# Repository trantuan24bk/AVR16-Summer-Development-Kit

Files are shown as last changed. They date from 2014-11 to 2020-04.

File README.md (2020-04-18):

# AVR16 Summer Development Kit
 Development kit for AVR 16-bit microcontrollers

**What included?**
- Programmer software: extreme burner avr
- USB driver: usbasp
- Altium project design files

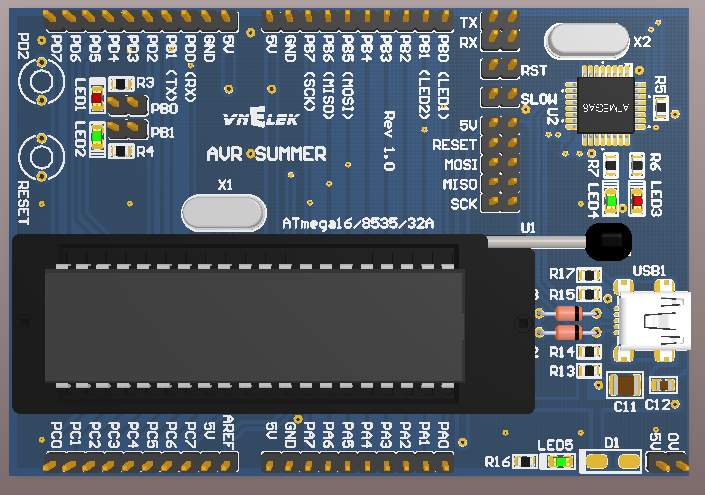
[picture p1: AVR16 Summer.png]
AVR16 Summer Development Kit


## Contribution

- Any contribute please make a pull request.
- Free to use for any purpose. Use at your own risk.

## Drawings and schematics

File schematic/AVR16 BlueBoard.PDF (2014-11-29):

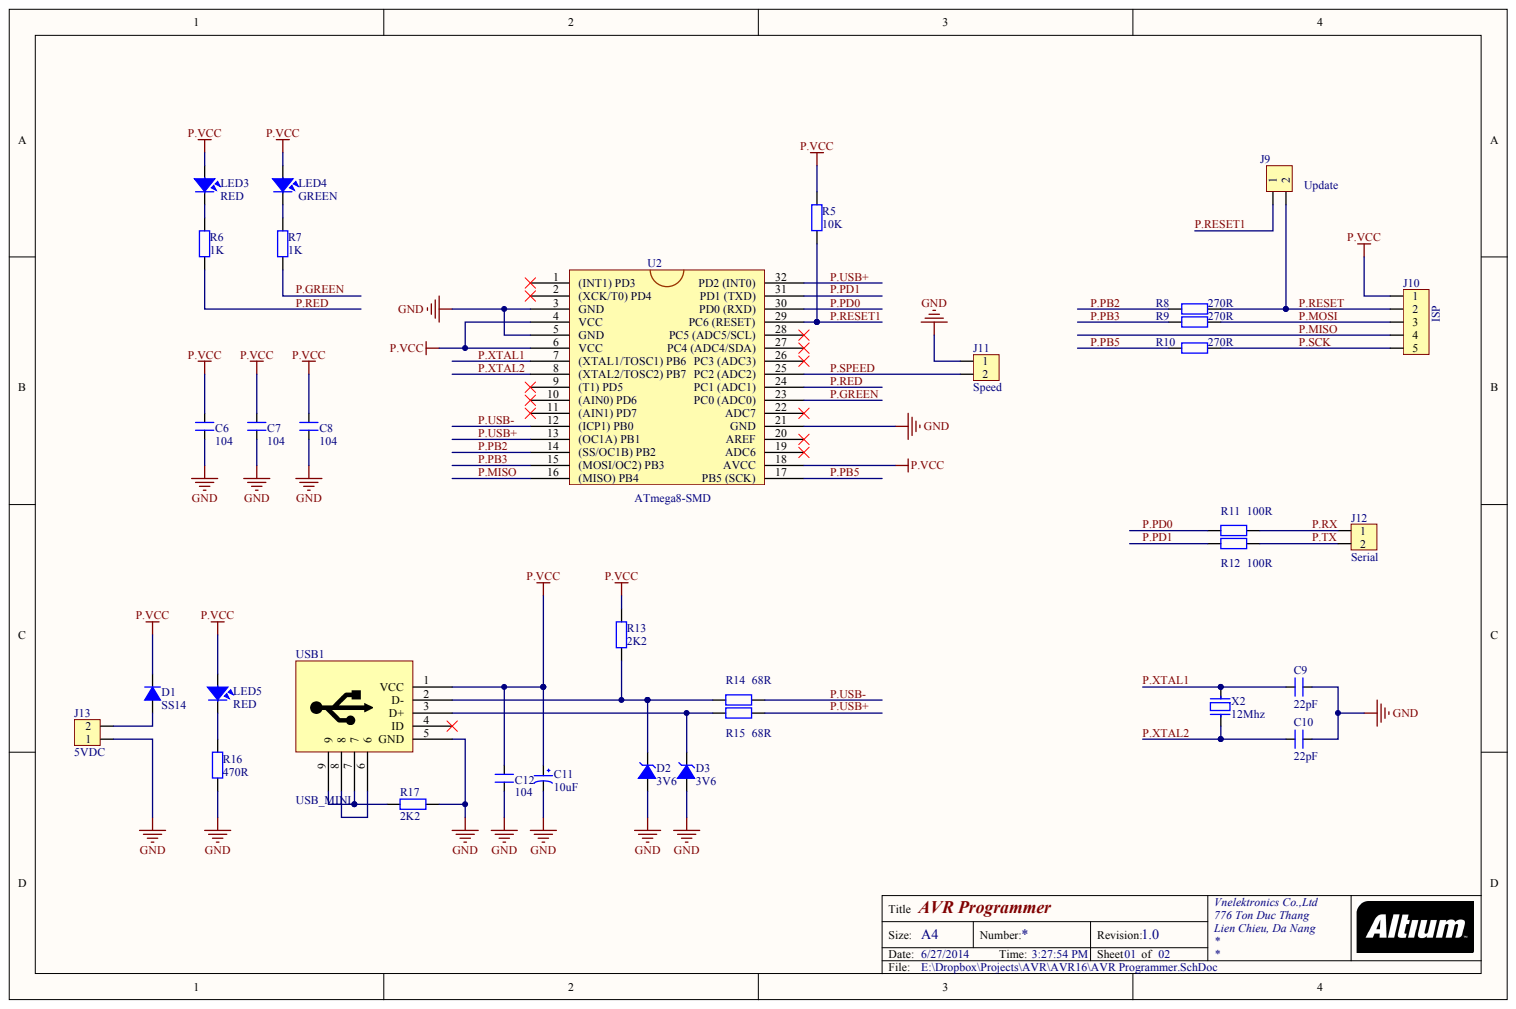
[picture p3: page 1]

4 D G | D G | D G | D G | D

Title | Vnelektro nics Co.,Ltd 7 7 6 To n D uc Th a n g Lien Chieu, D a Na n g * *

A4 Size: | N umber: | Revisio n :
Date: Time: | | Sheet 0 1 o f 0 2
File: E:\Dro p b o x\Projects\A VR\A VR1 6\A VR Pro grammer.Sch D o c

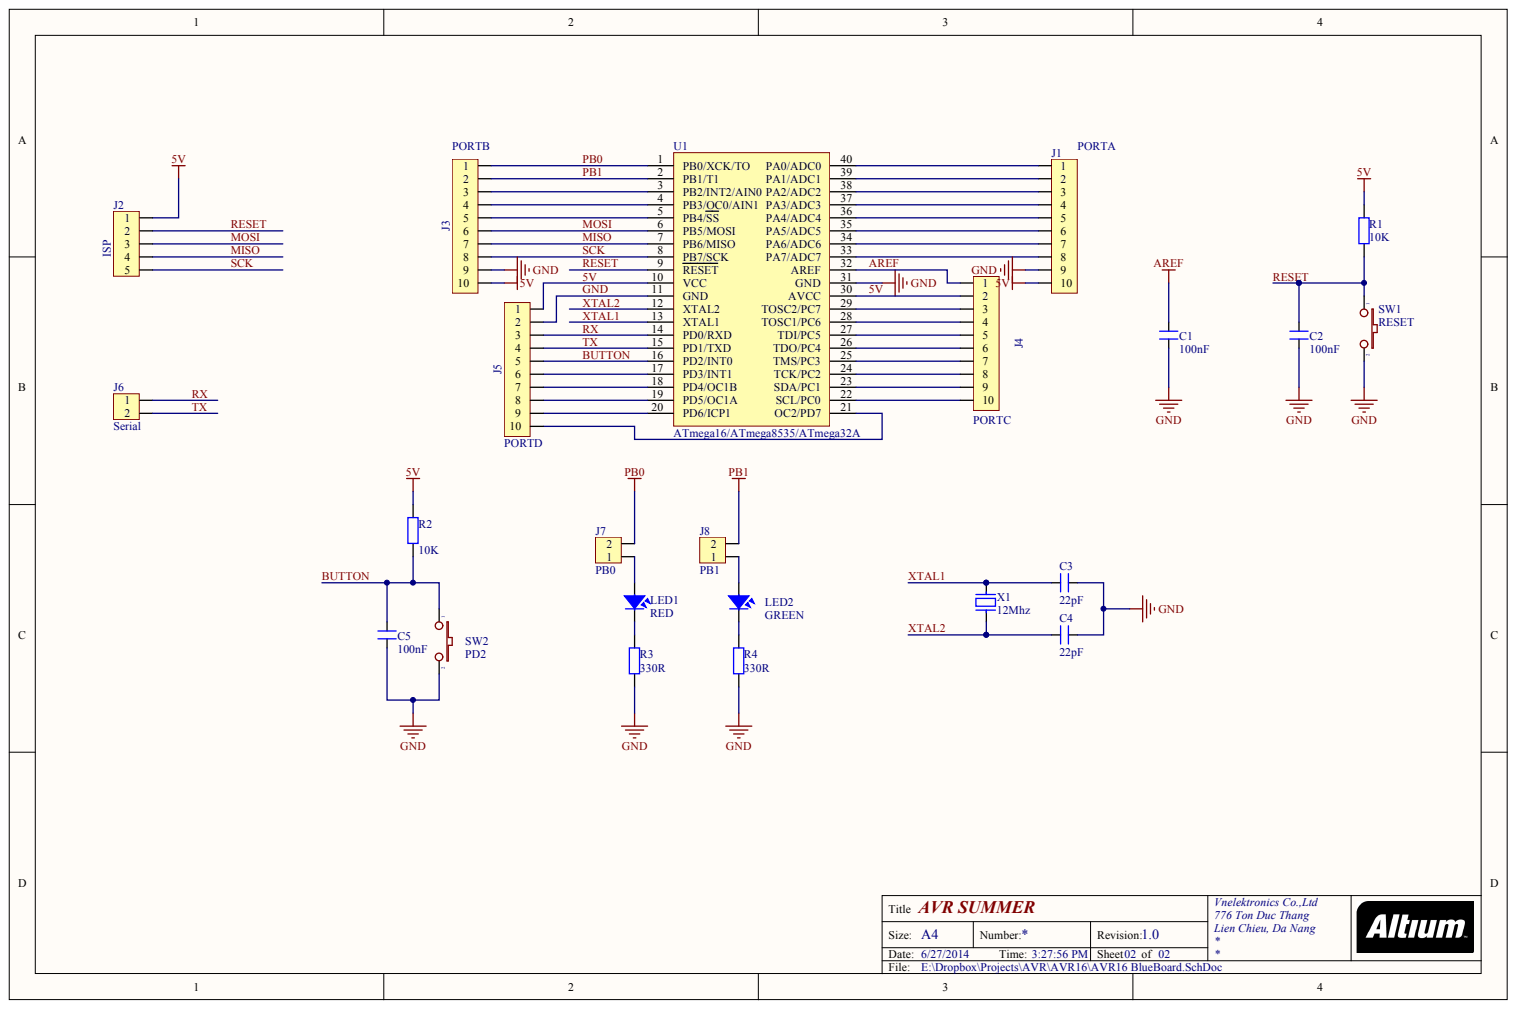
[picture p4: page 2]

5 1 0
D | 1 1 | | 5 V
XTAL2 XTAL1 | 1 2

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

A4 Size: | N umber: | Revisio n :
Date: Time: | | Sheet 0 2 o f 0 2
File: E:\Dro p b o x\Projects\A VR\A VR1 6\A VR1 6 BlueBoard.Sch D o c

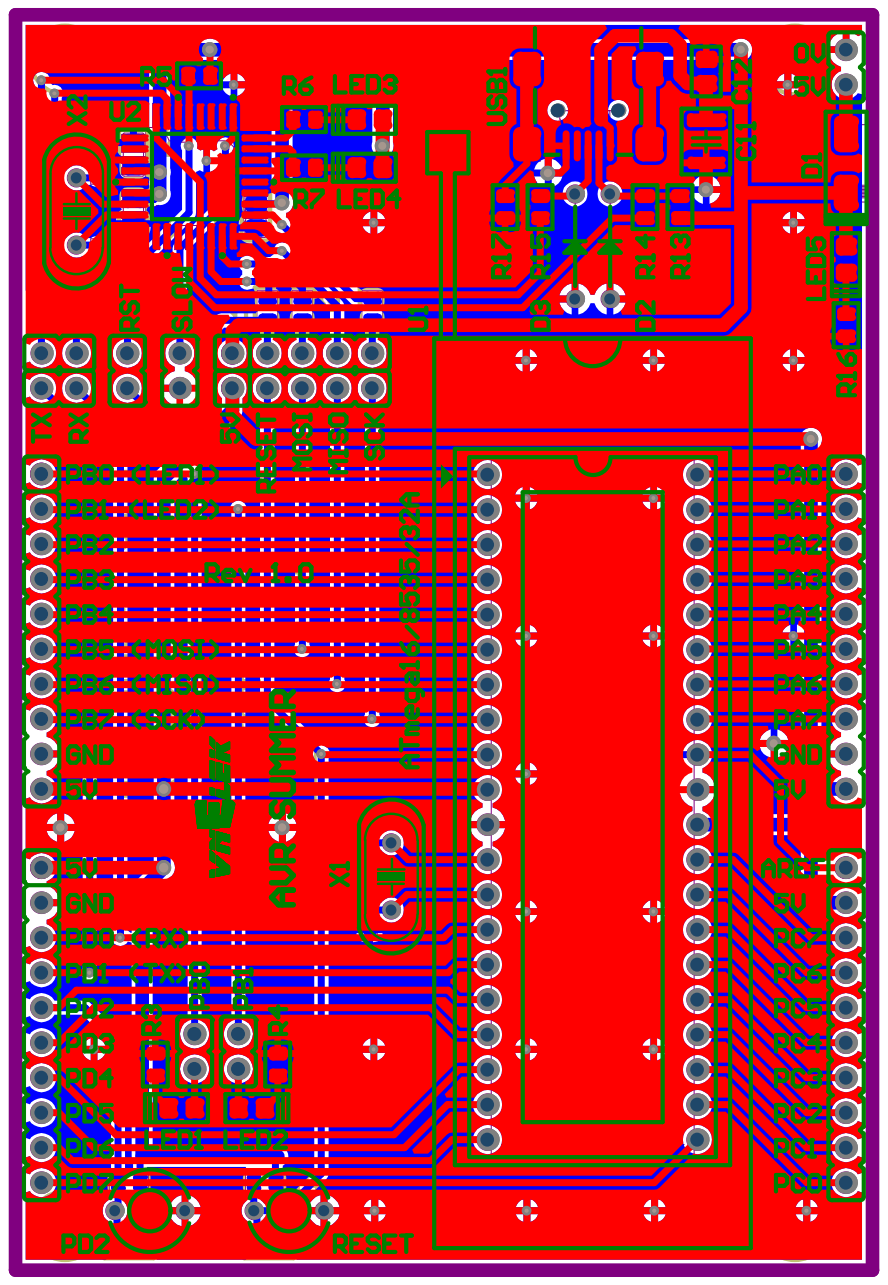
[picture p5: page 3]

Comment | Description | Designator | Footprint | LibRef | Quantity
100nF | Cap np 1pF - 472pF | C1, C2, C5 | C0805 | CN1 | 3
22pF | Cap np 1pF - 472pF | C3, C4, C9, C10 | C0603 | CN1 | 4
104 | Cap np 104 => 105pF | C6, C7, C8, C12 | C0805 | CN2 | 4
10uF | Cap P 0,1uF < 22uF , 16 - 50V | C11 | C1210 | CP1 | 1
SS14 | Diode 1A | D1 | SS14 | D1A | 1
3V6 | Diode Zenner | D2, D3 | 1N5223 | DZ | 2
PORTA | Header 10 | J1 | Header_10 | Hed10 | 1
ISP | Header 5 (Green) | J2, J10 | Header_5 | Hed5 | 2
PORTB | Header 10 | J3 | Header_10 | Hed10 | 1
PORTC | Header 10 | J4 | Header_10 | Hed10 | 1
PORTD | Header 10 | J5 | Header_10 | Hed10 | 1
Serial | Header 2 (Green) | J6, J12 | Header_2 | Hed2 | 2
PB0 | Header 2 (Green) | J7 | Header_2 | Hed2 | 1
PB1 | Header 2 (Green) | J8 | Header_2 | Hed2 | 1
Update | Header 2 (Green) | J9 | Header_2 | Hed2 | 1
Speed | Header 2 (Green) | J11 | Header_2 | Hed2 | 1
5VDC | Header 2 (Green) | J13 | Header_2 | Hed2 | 1
RED | LED Single colour Green and Red | LED1, LED3 | Led 0805R | LED | 2
GREEN | LED Single colour Green and Red | LED2, LED4 | Led 0805G | LED | 2
RED | LED Single colour Green and Red | LED5 | Led 0805G | LED | 1
Res2 | Resistor | R1, R2, R3, R4, R5, R6, R7, R8, R9, R10, R11, R12, R13, R14, R15, R16, R17 | RESC2012(0805) | Res2 | 17
RESET | Switch button 2 pin | SW1 | BUTTON 2PIN TRON | SW2 | 1
PD2 | Switch button 2 pin | SW2 | BUTTON 2PIN TRON | SW2 | 1
ATmega16/ATmega8535 /ATmega32A | 8-Bit AVR Microcontroller with 16K Bytes of In-System Programmable Flash Memory | U1 | de gat xanh dip 40 | Atmega16L | 1
ATmega8-SMD | High-performance, Low-power Atmel ® AVR ® 8-bit Microcontroller | U2 | ATMEGA_8_SMD | ATmega8_SMD_32pin | 1
USB_MINI | | USB1 | USBMNIB | USB_MINI | 1
12Mhz | Crystal For all Crystal 2piX1, X2 | | CRYSTAL | XT2 | 2

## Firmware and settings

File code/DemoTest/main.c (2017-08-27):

#include <avr/io.h>
#include <util/delay.h>

#define sbi(x,y) (x |= _BV(y)) 					// set bit
#define cbi(x,y) (x &= ~(_BV(y))) 				// clear bit
#define tbi(x,y) (x ^= _BV(y)) 					// toggle bit
#define is_high(x,y) ((x & _BV(y)) == _BV(y)) 	// (for input) checks if the input is high (Logic 1)

void main (void)
{
    DDRA = 0xFF;			// Dir Output
	DDRB = 0xFF;			// Dir Output
    DDRC = 0xFF;			// Dir Output
    DDRD = 0xFF;			// Dir Output
    
    DDRD &= ~_BV(PD2);		// Input button
    
    while(1) 
    {
    	if(is_high(PIND,PD2))
    	{
			PORTA = 0x00;
			PORTB = 0x00;
			PORTC = 0x00;
			PORTD = 0x00;
			_delay_ms(300);
			
			PORTA = 0xff;
			PORTB = 0xff;
			PORTC = 0xff;
			PORTD = 0xff;
			_delay_ms(300);			
    	}
		else
		{
			PORTA = 0x00;
			PORTB = 0x00;
			PORTC = 0x00;
			PORTD = 0x00;
		}		
    }
}

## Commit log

2014-11-29 AVR16 Summer Development Kit
    Phiên bản: 1.0
    Ngày cập nhật: 28/11/2014
    Tác giả: Trần Tuân
    Đã hoàn thiện:
    - Phiên bản layout đầu tiên cho kit.
    - Sử dụng chip ATmega8 để nạp chương trình.
    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
    [AVR Programmer.SchDoc, AVR16 BlueBoard.PrjPcb, AVR16 BlueBoard.SchDoc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]
2014-11-30 30/11/2014
    Chỉnh sửa dữ liệu do copy nhầm lẫn với module AVR8. Đây mới là dữ liệu chính xác của module AVR16
    [AVR Programmer.SchDoc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]
2017-08-27 Update module testing source.
    [AVR8 RedBoard.SchDoc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]
2020-04-18 Re-structure files and directory
    [AVR Programmer.SchDoc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]
